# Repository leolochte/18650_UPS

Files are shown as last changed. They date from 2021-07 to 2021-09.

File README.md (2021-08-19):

# 18650 UPS
My goal with this project is to power my development boards and experiments from a rechargable battery, so remaining a small footprint is obviously a key target. Ideally, the board should include conveniences like monitoring the power consumption and battery life. Charging should be done with standard USB Micro-B.

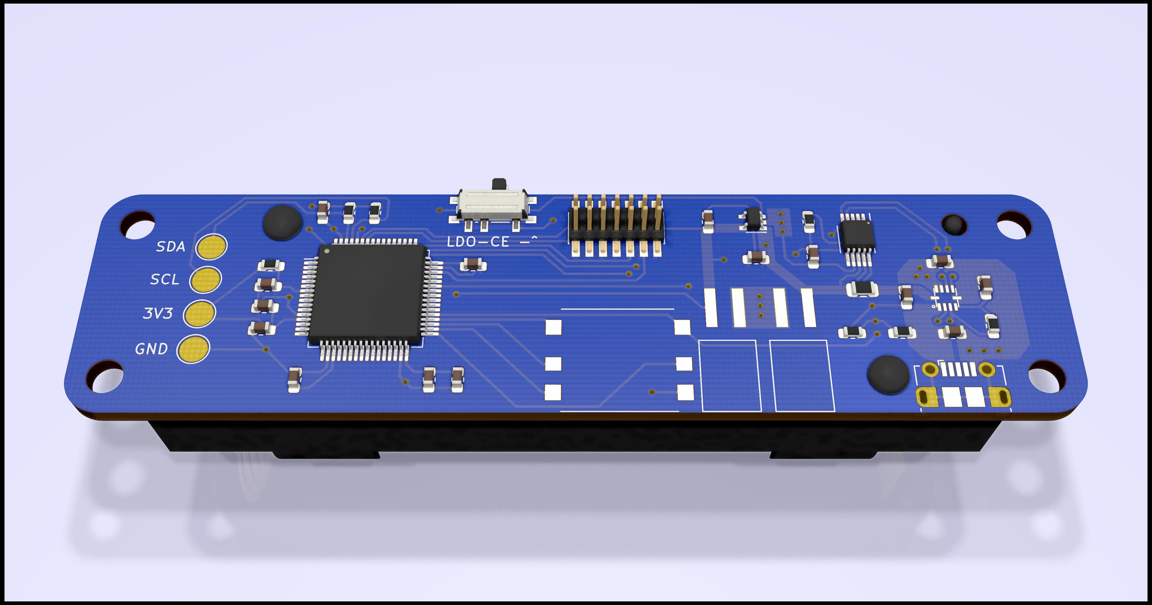
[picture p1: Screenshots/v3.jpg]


# Description
I decided for 18650 Li-Ion Cells as they are widely available and provide high capacity. Due to their metal casing they are also more robust than normal hobby grade LiPo batteries.
Of course, there are countless 18650 compatible supply boards for projects already, but they all miss certain features or raise serious quality and safety concerns.

So i set out to design my own PCB that mounts directly to the back of a single cell holder.

# Safety
As all Li-Ion batteries should be treated with great care, my desired safety features are:

- Overcharge cutoff
- Safety timer during charge phase
- Overcurrent protection / Current limiting
- Short circuit protection
- **Configurable** Under-voltge cutoff
- Battery disconnect during storage
- Temperature warnings

# Part Selection

- **MP2667**        - I2C programmable Charge IC with heaps of safety features and output current limiting
- **INA237**        - 16-Bit current, power, temperature and voltage monitor with I2C Interface
- **STM32L151RCT6** - Simply because i had them lying around
- **1.3" OLED**     - To configure the charger and display sensor data

# Current State Of Project

The non-ideal switchmode regulator layout and method of seperatig the chargin IC and protection IC resulted in problems. In the current version switchmodes are omitted and all safety features are integrated in one high quality IC. The monitoring capabilities have been enhanced and a bigger display replaced the old one.

All parts for version 3 are ordered. Patiently waiting for snail post to arrive...

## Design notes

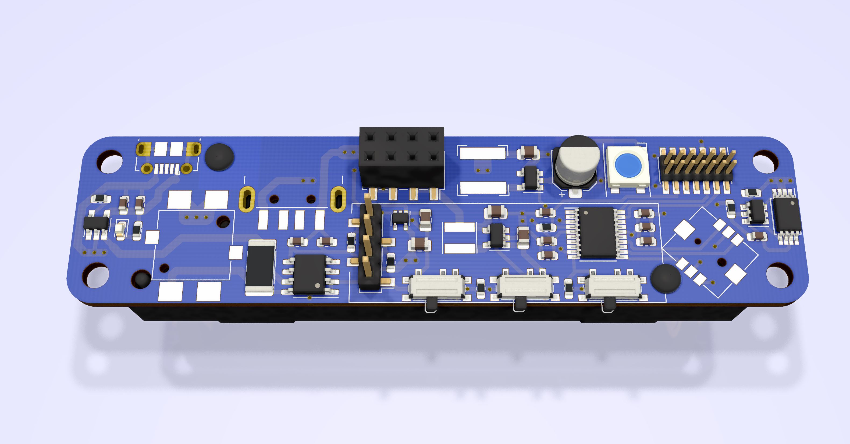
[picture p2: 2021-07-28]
Screenshots/V2.JPG

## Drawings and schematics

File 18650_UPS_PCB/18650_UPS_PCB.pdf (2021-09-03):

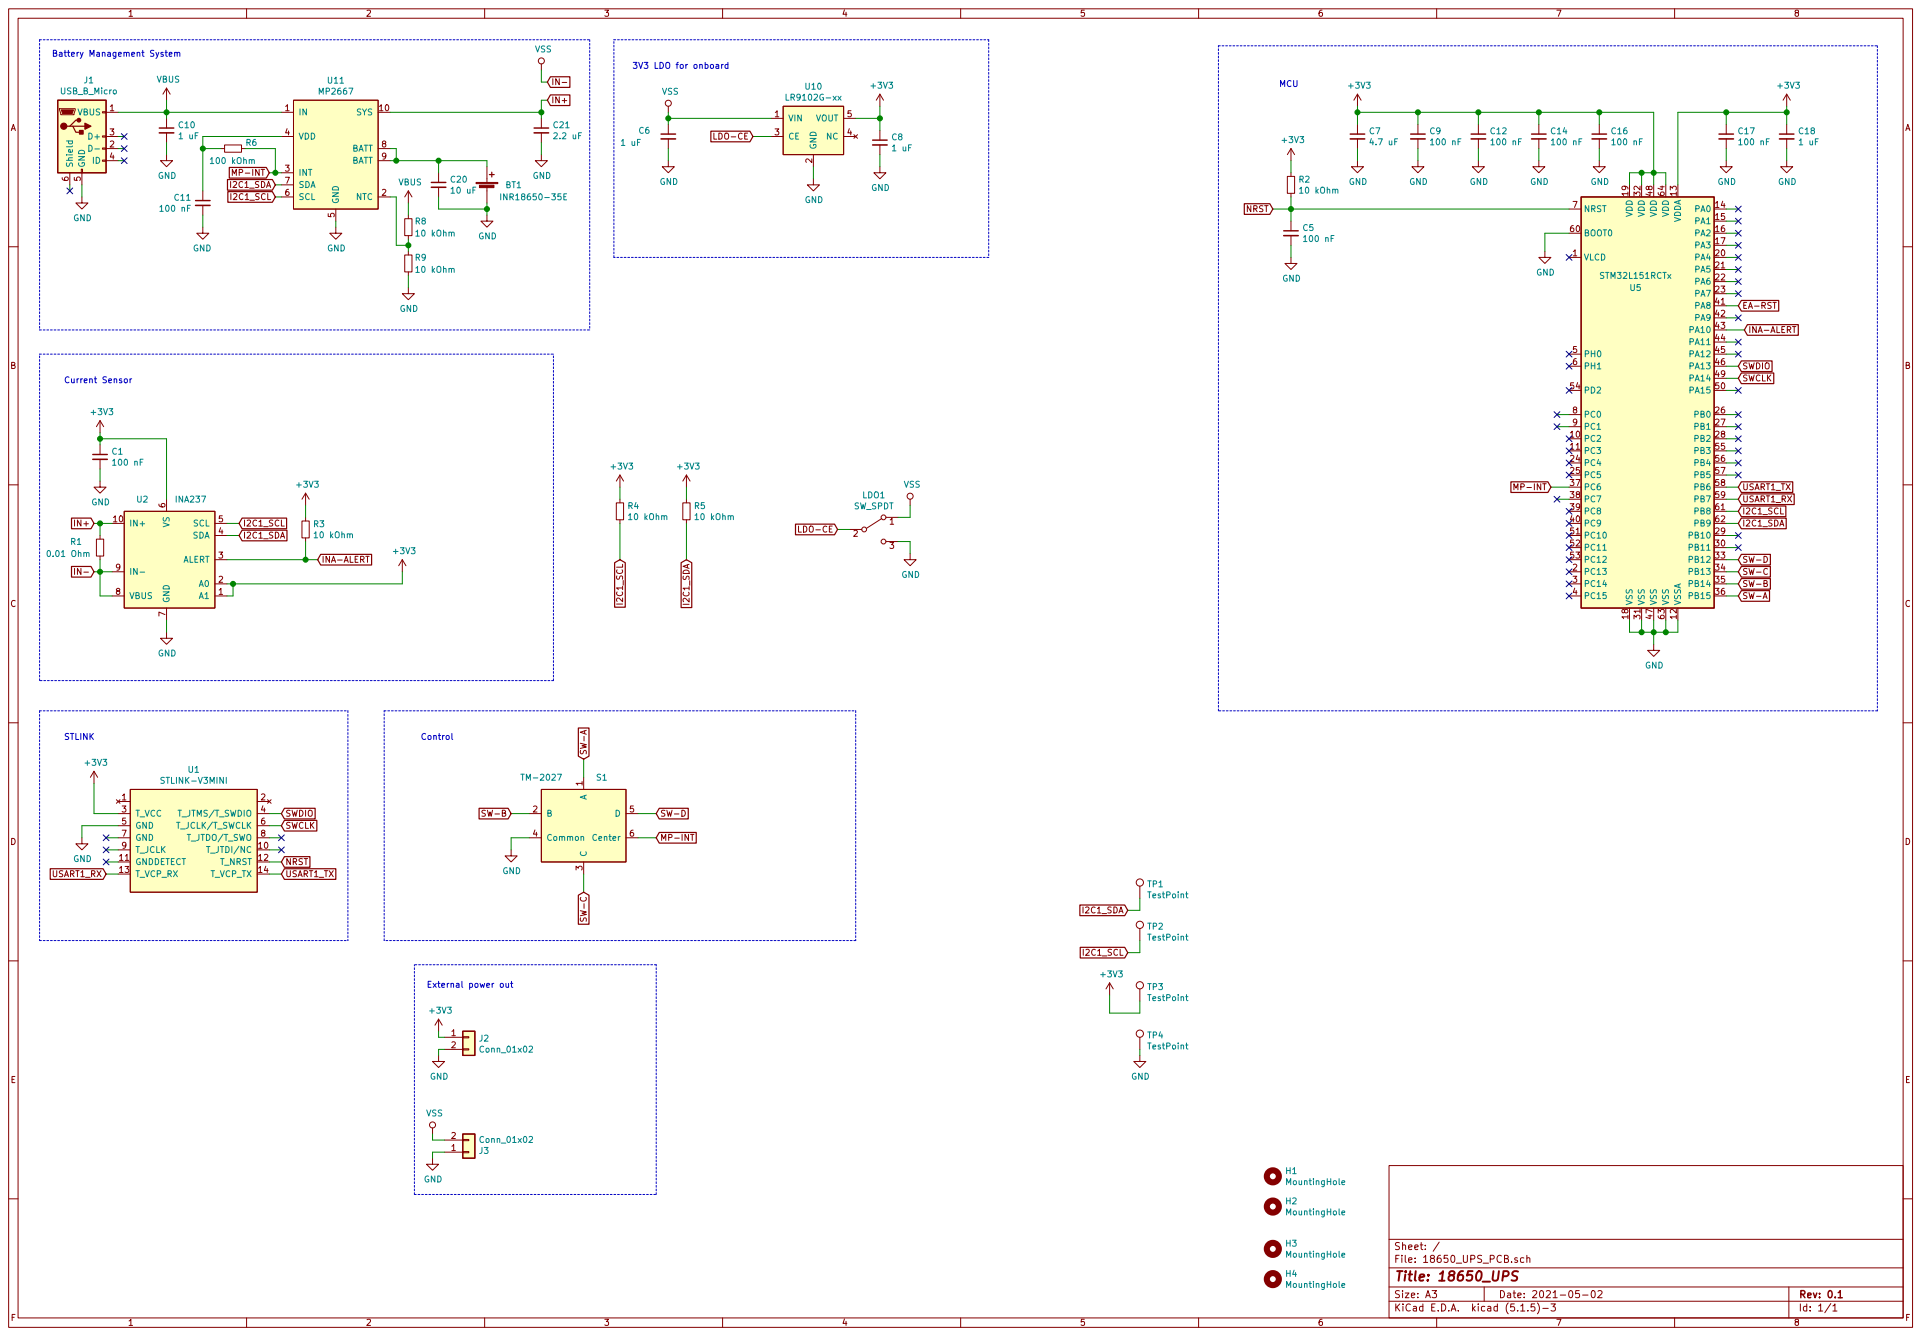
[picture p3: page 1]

3V3 LDO for onboard Battery Management System

5 SCL 6 SDA 7 BATT 8 BATT 9 U11 MP2667 A1 1

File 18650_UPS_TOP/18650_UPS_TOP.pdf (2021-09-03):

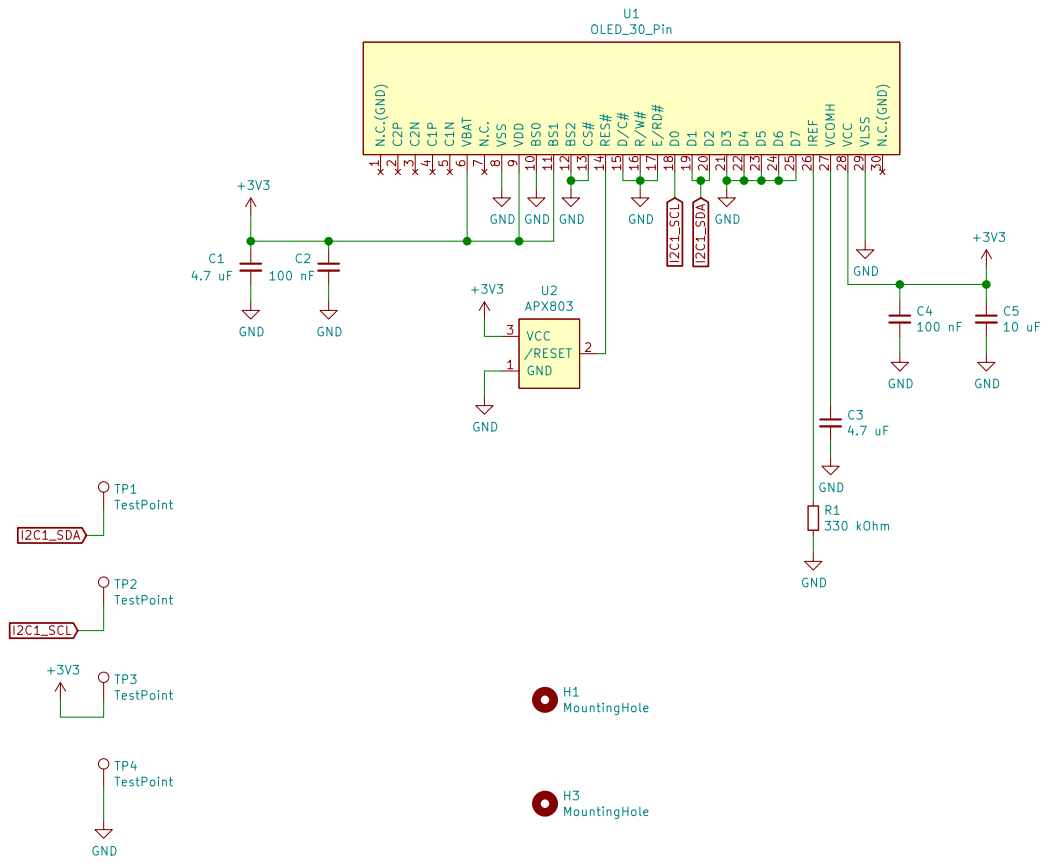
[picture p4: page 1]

9 U1 OLED_30_Pin +3V3 TP3 TestPoint TP4 TestPoint TP2 TestPoint TP1 TestPoint H3MountingHole

2 D2 20 D3 21 D4 22 D5 23 D6 24 D7 25 IREF 26 VCOMH 27 VCC 28 VLSS 29 C2N

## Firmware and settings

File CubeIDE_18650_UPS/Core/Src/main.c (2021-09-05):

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
/* Includes ------------------------------------------------------------------*/
#include "main.h"

/* USER CODE BEGIN Includes */
#include "ssd1306.h"
#include "stdio.h"
/* USER CODE END Includes */

I2C_HandleTypeDef hi2c1;

TIM_HandleTypeDef htim2;

UART_HandleTypeDef huart1;

/* USER CODE BEGIN PV */
uint8_t aRxBuffer[3];
uint8_t TxBuffer[2];
char charBuffer[20];
uint16_t temp;

volatile uint8_t read_state = 0;
uint8_t state_SW_U = 0;
uint8_t state_SW_D = 0;
uint8_t state_SW_L = 0;
uint8_t state_SW_R = 0;

volatile uint8_t contrast = 0xFF;
volatile uint8_t charge_enable = 1;
volatile uint8_t usb_version = 2;
/* USER CODE END PV */

void SystemClock_Config(void);
static void MX_GPIO_Init(void);
static void MX_USART1_UART_Init(void);
static void MX_I2C1_Init(void);
static void MX_TIM2_Init(void);
/**
  * @brief  The application entry point.
  * @retval int
  */
int main(void)
{
  /* MCU Configuration--------------------------------------------------------*/

  /* Reset of all peripherals, Initializes the Flash interface and the Systick. */
  HAL_Init();

  /* Configure the system clock */
  SystemClock_Config();

  /* Initialize all configured peripherals */
  MX_GPIO_Init();
  MX_USART1_UART_Init();
  MX_I2C1_Init();
  MX_TIM2_Init();
  /* USER CODE BEGIN 2 */
  ssd1306_Init();

  //resetting ina237
  TxBuffer[0] = 0x80;
  TxBuffer[1] = 0x00;
  HAL_I2C_Mem_Write(&hi2c1, 0x45<<1, 0x00, 1, TxBuffer, sizeof(TxBuffer), 1000);

  //setting adc range
  TxBuffer[0] = 0x00;
  TxBuffer[1] = 0x10;
  HAL_I2C_Mem_Write(&hi2c1, 0x45<<1, 0x00, 1, TxBuffer, sizeof(TxBuffer), 1000);

  //calibrating shunt register
  TxBuffer[0] = 0x07;
  TxBuffer[1] = 0xD0;
  HAL_I2C_Mem_Write(&hi2c1, 0x45<<1, 0x02, 1, TxBuffer, sizeof(TxBuffer), 1000);

  //adc_config
  HAL_I2C_Mem_Read(&hi2c1, 0x45<<1, 0x01, 1, aRxBuffer, sizeof(aRxBuffer), 1000);
  temp = (aRxBuffer[0]<<8) | aRxBuffer[1];
  TxBuffer[0] = aRxBuffer[0];
  TxBuffer[1] = aRxBuffer[1] | 0x05;
  HAL_I2C_Mem_Write(&hi2c1, 0x45<<1, 0x01, 1, TxBuffer, sizeof(TxBuffer), 1000);

  //charge config default
  HAL_I2C_Mem_Read(&hi2c1, 0x09<<1, 0x01, 1, aRxBuffer, sizeof(aRxBuffer), 1000);
  TxBuffer[0] = 0b00000100; 	//charge enable and UVLO 2.8V
  TxBuffer[1] = 0x00;
  HAL_I2C_Mem_Write(&hi2c1, 0x09<<1, 0x01, 1, TxBuffer, 1, 1000);
  HAL_I2C_Mem_Read(&hi2c1, 0x09<<1, 0x01, 1, aRxBuffer, sizeof(aRxBuffer), 1000);

  //setting initial charge curretn to usb 2 compliant
  TxBuffer[0] = 0b01001011;
  TxBuffer[1] = 0x00;
  HAL_I2C_Mem_Write(&hi2c1, 0x09<<1, 0x00, 1, TxBuffer, 1, 1000);
  TxBuffer[0] = 0b00001110;
  TxBuffer[1] = 0x00;
  HAL_I2C_Mem_Write(&hi2c1, 0x09<<1, 0x02, 1, TxBuffer, 1, 1000);

  /* USER CODE END 2 */

  /* Infinite loop */
  /* USER CODE BEGIN WHILE */
  while (1)
  {
    /* USER CODE END WHILE */

    /* USER CODE BEGIN 3 */


	  ssd1306_Fill(Black);

	  switch (read_state) {
	  	  case 0:
	  		  //vbus
			  HAL_I2C_Mem_Read(&hi2c1, 0x45<<1, 0x05, 1, aRxBuffer, sizeof(aRxBuffer), 1000);
			  temp = 3.125*(float)((aRxBuffer[0]<<8) | aRxBuffer[1]);
			  sprintf(charBuffer, "%u mV", temp);
			  ssd1306_SetCursor(0, 14);
			  ssd1306_WriteString(charBuffer, Font_11x18, White);
			  sprintf(charBuffer, "Voltage:");
			  ssd1306_SetCursor(0, 0);
			  ssd1306_WriteString(charBuffer, Font_7x10, White);
			  ssd1306_DrawRectangle(124, 0, 127, 3, White);
			  ssd1306_DrawRectangle(125, 1, 126, 2, White);
	  		  break;
	  	  case 1:
			  //current
			  HAL_I2C_Mem_Read(&hi2c1, 0x45<<1, 0x07, 1, aRxBuffer, sizeof(aRxBuffer), 1000);
			  temp = 0.0610352*(float)((aRxBuffer[0]<<8) | aRxBuffer[1]);
			  sprintf(charBuffer, "%u mA", temp);
			  ssd1306_SetCursor(0, 14);
			  ssd1306_WriteString(charBuffer, Font_11x18, White);
			  sprintf(charBuffer, "Current output:");
			  ssd1306_SetCursor(0, 0);
			  ssd1306_WriteString(charBuffer, Font_7x10, White);
			  ssd1306_DrawRectangle(124, 4, 127, 7, White);
			  ssd1306_DrawRectangle(125, 5, 126, 6, White);
	  		  break;
	  	  case 2:
			  //power
			  HAL_I2C_Mem_Read(&hi2c1, 0x45<<1, 0x08, 1, aRxBuffer, sizeof(aRxBuffer), 1000);
			  temp = 0.2*0.0610352*(float)((aRxBuffer[0]<<16) | aRxBuffer[1]<<8 | aRxBuffer[0]);
			  sprintf(charBuffer, "%u mW", temp);
			  ssd1306_SetCursor(0, 14);
			  ssd1306_WriteString(charBuffer, Font_11x18, White);
			  sprintf(charBuffer, "Power output:");
			  ssd1306_SetCursor(0, 0);
			  ssd1306_WriteString(charBuffer, Font_7x10, White);
			  ssd1306_DrawRectangle(124, 8, 127, 11, White);
			  ssd1306_DrawRectangle(125, 9, 126, 10, White);
			  break;
	  	  case 3:
			  //dietemp
			  HAL_I2C_Mem_Read(&hi2c1, 0x45<<1, 0x06, 1, aRxBuffer, sizeof(aRxBuffer), 1000);
			  temp = 0.125*(float)((aRxBuffer[0]<<8) | aRxBuffer[1]);
			  temp = temp>>4;
			  sprintf(charBuffer, "%u C", temp);
			  ssd1306_SetCursor(0, 14);
			  ssd1306_WriteString(charBuffer, Font_11x18, White);
			  sprintf(charBuffer, "Board temperature:");
			  ssd1306_SetCursor(0, 0);
			  ssd1306_WriteString(charBuffer, Font_7x10, White);
			  ssd1306_DrawRectangle(124, 12, 127, 15, White);
			  ssd1306_DrawRectangle(125, 13, 126, 14, White);
			  break;
	  	  case 4:
			  //charge status
			  HAL_I2C_Mem_Read(&hi2c1, 0x09<<1, 0x07, 1, aRxBuffer, sizeof(aRxBuffer), 1000);
			  temp = (aRxBuffer[0] & 0b00011000)>>3;
			  switch (temp) {
				  case 0:
					  sprintf(charBuffer, "No charger");
					  ssd1306_SetCursor(0, 14);
					  ssd1306_WriteString(charBuffer, Font_11x18, White);
					  break;
				  case 1:
					  sprintf(charBuffer, "Pre charge");
					  ssd1306_SetCursor(0, 14);
					  ssd1306_WriteString(charBuffer, Font_11x18, White);
					  break;
				  case 2:
					  sprintf(charBuffer, "Charging...");
					  ssd1306_SetCursor(0, 14);
					  ssd1306_WriteString(charBuffer, Font_11x18, White);
					  break;
				  case 3:
					  sprintf(charBuffer, "Done!");
					  ssd1306_SetCursor(0, 14);
					  ssd1306_WriteString(charBuffer, Font_11x18, White);
					  break;
				  default:
					  break;
			  }
			  sprintf(charBuffer, "Charge status:");
			  ssd1306_SetCursor(0, 0);
			  ssd1306_WriteString(charBuffer, Font_7x10, White);
			  ssd1306_DrawRectangle(124, 16, 127, 19, White);
			  ssd1306_DrawRectangle(125, 17, 126, 18, White);
			  break;
		  case 5:
			  if (charge_enable == 0) {
				  sprintf(charBuffer, "OFF");
				  ssd1306_SetCursor(1, 14);
				  ssd1306_WriteString(charBuffer, Font_11x18, Black);
				  sprintf(charBuffer, "ON ");
				  ssd1306_SetCursor(38, 14);
				  ssd1306_WriteString(charBuffer, Font_11x18, White);
			  } else if (charge_enable == 1) {
				  sprintf(charBuffer, "OFF");
				  ssd1306_SetCursor(1, 14);
				  ssd1306_WriteString(charBuffer, Font_11x18, White);
				  sprintf(charBuffer, "ON ");
				  ssd1306_SetCursor(38, 14);
				  ssd1306_WriteString(charBuffer, Font_11x18, Black);
			  }
			  ssd1306_DrawRectangle(0, 13, 70, 31, White);


			  sprintf(charBuffer, "Charge control:");
			  ssd1306_SetCursor(0, 0);
			  ssd1306_WriteString(charBuffer, Font_7x10, White);
			  ssd1306_DrawRectangle(124, 20, 127, 23, White);
			  ssd1306_DrawRectangle(125, 21, 126, 22, White);
			  break;
		  case 6:
			  if (usb_version == 2) {
				  sprintf(charBuffer, "0.5A");
				  ssd1306_SetCursor(1, 14);
				  ssd1306_WriteString(charBuffer, Font_11x18, Black);
				  sprintf(charBuffer, "1.0A");
				  ssd1306_SetCursor(50, 14);
				  ssd1306_WriteString(charBuffer, Font_11x18, White);
			  } else if (usb_version == 3) {
				  sprintf(charBuffer, "0.5A");
				  ssd1306_SetCursor(1, 14);
				  ssd1306_WriteString(charBuffer, Font_11x18, White);
				  sprintf(charBuffer, "1.0A ");
				  ssd1306_SetCursor(50, 14);
				  ssd1306_WriteString(charBuffer, Font_11x18, Black);
			  }
			  ssd1306_DrawRectangle(0, 13, 104, 31, White);

			  sprintf(charBuffer, "USB current limit:");
			  ssd1306_SetCursor(0, 0);
			  ssd1306_WriteString(charBuffer, Font_7x10, White);
			  ssd1306_DrawRectangle(124, 24, 127, 27, White);
			  ssd1306_DrawRectangle(125, 25, 126, 26, White);
			  break;
		  case 7:
			  switch (contrast) {
				  case 255:
					  sprintf(charBuffer, "100");
					  break;
				  case 191:
					  sprintf(charBuffer, "75");
					  break;
				  case 127:
					  sprintf(charBuffer, "50");
					  break;
				  case 63:
					  sprintf(charBuffer, "25");
					  break;
				  case 0:
					  sprintf(charBuffer, "0");
					  break;
				  default:
					  break;
			  }

			  ssd1306_SetCursor(0, 14);
			  ssd1306_WriteString(charBuffer, Font_11x18, White);
			  sprintf(charBuffer, "Screen brightness:");
			  ssd1306_SetCursor(0, 0);
			  ssd1306_WriteString(charBuffer, Font_7x10, White);
			  ssd1306_DrawRectangle(124, 28, 127, 31, White);
			  ssd1306_DrawRectangle(125, 29, 126, 30, White);
		  	  break;
	  	  default:
		  	  break;
	  }

	  ssd1306_UpdateScreen();

	  HAL_Delay(100);
  }
  /* USER CODE END 3 */
}

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
/* USER CODE BEGIN 4 */
void HAL_GPIO_EXTI_Callback(uint16_t GPIO_Pin) {
	switch (GPIO_Pin) {
		case SW_U_Pin:
			state_SW_U = 1;
			HAL_TIM_Base_Start_IT(&htim2);
			break;
		case SW_D_Pin:
			state_SW_D = 1;
			HAL_TIM_Base_Start_IT(&htim2);
			break;
		case SW_L_Pin:
			state_SW_L = 1;
			HAL_TIM_Base_Start_IT(&htim2);
			break;
		case SW_R_Pin:
			state_SW_R = 1;
			HAL_TIM_Base_Start_IT(&htim2);
			break;
		default:
			break;
	}
}

void HAL_TIM_PeriodElapsedCallback(TIM_HandleTypeDef *htim)
{
  if (htim == &htim2) {
	 if (state_SW_U == 1 && HAL_GPIO_ReadPin(SW_U_GPIO_Port, SW_U_Pin) == GPIO_PIN_RESET) {
		 state_SW_U = 0;
		 HAL_TIM_Base_Stop_IT(&htim2);

		 if (read_state == 0) {
			 //read_state = 7;
		 } else {
			 read_state--;
		 }
	 }
	 if (state_SW_D == 1 && HAL_GPIO_ReadPin(SW_D_GPIO_Port, SW_D_Pin) == GPIO_PIN_RESET) {
		 state_SW_D = 0;
		 HAL_TIM_Base_Stop_IT(&htim2);

		 if (read_state == 7) {
			 //read_state = 0;
		 } else {
			 read_state++;
		 }
	 }
	 if (state_SW_L == 1 && HAL_GPIO_ReadPin(SW_L_GPIO_Port, SW_L_Pin) == GPIO_PIN_RESET) {
		 state_SW_L = 0;
		 HAL_TIM_Base_Stop_IT(&htim2);

		 switch (read_state) {
		 	 case 5:
		 		 charge_enable = 0;

		 		 HAL_I2C_Mem_Read(&hi2c1, 0x09<<1, 0x01, 1, aRxBuffer, sizeof(aRxBuffer), 1000);
		 		 TxBuffer[0] = aRxBuffer[0] | 0b00001000;
		 		 TxBuffer[1] = 0x00;
		 		 HAL_I2C_Mem_Write(&hi2c1, 0x09<<1, 0x01, 1, TxBuffer, 1, 1000);
		 		 HAL_I2C_Mem_Read(&hi2c1, 0x09<<1, 0x01, 1, aRxBuffer, sizeof(aRxBuffer), 1000);
		 		 break;
		 	 case 6:
		 		 usb_version = 2;
		 		 TxBuffer[0] = 0b01001011;
				 TxBuffer[1] = 0x00;
				 HAL_I2C_Mem_Write(&hi2c1, 0x09<<1, 0x00, 1, TxBuffer, 1, 1000);
				 TxBuffer[0] = 0b00001110;
				 TxBuffer[1] = 0x00;
				 HAL_I2C_Mem_Write(&hi2c1, 0x09<<1, 0x02, 1, TxBuffer, 1, 1000);
		 		 break;
		 	 case 7:
		 		 if (contrast > 63) {
		 			 contrast = contrast-64;
		 		 	 ssd1306_SetContrast(contrast);
		 		 } else if (contrast == 63) {
		 			 contrast = contrast-63;
		 			 ssd1306_SetContrast(contrast);
		 		 }
		 		 break;
		 	 default:
		 		 break;
		 }


	 }
	 if (state_SW_R == 1 && HAL_GPIO_ReadPin(SW_R_GPIO_Port, SW_R_Pin) == GPIO_PIN_RESET) {
		 state_SW_R = 0;
		 HAL_TIM_Base_Stop_IT(&htim2);

		 switch (read_state) {
		 	 case 5:
		 		 charge_enable = 1;
		 		 HAL_I2C_Mem_Read(&hi2c1, 0x09<<1, 0x01, 1, aRxBuffer, sizeof(aRxBuffer), 1000);
				 TxBuffer[0] = aRxBuffer[0] & 0b11110111;
				 TxBuffer[1] = 0x00;
				 HAL_I2C_Mem_Write(&hi2c1, 0x09<<1, 0x01, 1, TxBuffer, 1, 1000);
				 HAL_I2C_Mem_Read(&hi2c1, 0x09<<1, 0x01, 1, aRxBuffer, sizeof(aRxBuffer), 1000);
		 		 break;
		 	 case 6:
		 		 usb_version = 3;
		 		 TxBuffer[0] = 0b01001111;
				 TxBuffer[1] = 0x00;
				 HAL_I2C_Mem_Write(&hi2c1, 0x09<<1, 0x00, 1, TxBuffer, 1, 1000);
				 TxBuffer[0] = 0b00011100;
				 TxBuffer[1] = 0x00;
				 HAL_I2C_Mem_Write(&hi2c1, 0x09<<1, 0x02, 1, TxBuffer, 1, 1000);
		 		 break;
		 	 case 7:
		 		 if (contrast == 0) {
		 			 contrast = contrast+63;
		 		 	 ssd1306_SetContrast(contrast);
		 		 } else if (contrast > 0 && contrast != 255) {
		 			 contrast = contrast+64;
					 ssd1306_SetContrast(contrast);
		 		 }
		 		 break;
		 	 default:
		 		 break;
		 }
	 }
  }
}
/* USER CODE END 4 */
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


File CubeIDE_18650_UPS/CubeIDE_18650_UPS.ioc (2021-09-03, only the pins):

Mcu.UserName=STM32L151RCTx
PA13.Signal=SYS_JTMS-SWDIO
PA14.Signal=SYS_JTCK-SWCLK
PB12.GPIO_Label=SW_R
PB12.Signal=GPXTI12
PB13.GPIO_Label=SW_D
PB13.Signal=GPXTI13
PB14.GPIO_Label=SW_L
PB14.Signal=GPXTI14
PB15.GPIO_Label=SW_U
PB15.Signal=GPXTI15
PB6.Signal=USART1_TX
PB7.Signal=USART1_RX
PB8.Signal=I2C1_SCL
PB9.Signal=I2C1_SDA

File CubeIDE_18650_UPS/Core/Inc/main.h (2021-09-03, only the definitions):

#define SW_R_Pin GPIO_PIN_12
#define SW_R_GPIO_Port GPIOB
#define SW_R_EXTI_IRQn EXTI15_10_IRQn
#define SW_D_Pin GPIO_PIN_13
#define SW_D_GPIO_Port GPIOB
#define SW_D_EXTI_IRQn EXTI15_10_IRQn
#define SW_L_Pin GPIO_PIN_14
#define SW_L_GPIO_Port GPIOB
#define SW_L_EXTI_IRQn EXTI15_10_IRQn
#define SW_U_Pin GPIO_PIN_15
#define SW_U_GPIO_Port GPIOB
#define SW_U_EXTI_IRQn EXTI15_10_IRQn

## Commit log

2021-05-01 created kicad project
    [18650_UPS_PCB.kicad_pcb, 18650_UPS_PCB.sch]
2021-05-02 added main components
    [18650_UPS_PCB.sch]
2021-05-03 reworked schematic
    [18650_UPS_PCB.sch]
2021-05-05 moved some components around and added st link
    [18650_UPS_PCB.sch]
2021-05-10 removed IoT board connectors
    [18650_UPS_PCB.kicad_pcb, 18650_UPS_PCB.sch, connectors.sch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]
2021-05-12 first routing done
    [18650_UPS_PCB.kicad_pcb, 18650_UPS_PCB.sch, mcu_sense.sch]
2021-05-12 test of branch
    [18650_UPS_PCB.sch]
2021-05-13 layout almost done
    [18650_UPS_PCB.kicad_pcb, 18650_UPS_PCB.sch, connectors.sch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]
2021-05-17 routing done
    [18650_UPS_PCB.kicad_pcb, 18650_UPS_PCB.sch, power.sch]
2021-05-17 schematic organizing
    [18650_UPS_PCB.sch]
2021-05-17 changed resistor values tps63000
    [18650_UPS_PCB.kicad_pcb, 18650_UPS_PCB.sch, BOM.xlsx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]
2021-05-24 deleted lcsc shopping cart files
    [LCSC_Exported_20210517_180502.xlsx, LCSC_Exported_20210517_183229.xlsx, LCSC_Exported_20210517_221247.xlsx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]
2021-06-12 removed some not needed files
    [external.sch, rpi.sch]
2021-06-12 v2 layout started
    [18650_UPS_PCB.kicad_pcb, 18650_UPS_PCB.sch, power.sch]
2021-06-12 all components on board
    [18650_UPS_PCB.kicad_pcb, 18650_UPS_PCB.sch]
2021-06-17 v2 layout complete and started routing
    [18650_UPS_PCB.kicad_pcb, 18650_UPS_PCB.sch]
2021-06-21 1 net left
    [18650_UPS_PCB.kicad_pcb]
2021-06-21 routing cleanup
    [18650_UPS_PCB.kicad_pcb]
2021-06-22 cleaned routing significantly
    [18650_UPS_PCB.kicad_pcb, 18650_UPS_PCB.sch]
2021-06-22 v2 ordered
    [18650_UPS_PCB-B_Cu.gbr, 18650_UPS_PCB-B_Mask.gbr, 18650_UPS_PCB-B_Paste.gbr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]
2021-07-29 base for v2 with new bms and sense ic
    [18650_UPS_PCB.kicad_pcb, 18650_UPS_PCB.sch]
2021-07-30 reworked schematic with new components
    5V Boost missing
    [18650_UPS_PCB.sch]
2021-07-30 schematic done
    [18650_UPS_PCB.sch]
2021-07-30 savepoint before messing up pcbnew
    [18650_UPS_PCB.kicad_pcb, 18650_UPS_PCB.sch]
2021-07-31 all parts on pcb
    [18650_UPS_PCB.kicad_pcb, 18650_UPS_PCB.sch]
2021-08-01 placed all components
    [18650_UPS_PCB.kicad_pcb, 18650_UPS_PCB.sch]
2021-08-02 changed to ina 237/239
    [18650_UPS_PCB.kicad_pcb, 18650_UPS_PCB.sch]
2021-08-02 minor changes in layout
    [18650_UPS_PCB.kicad_pcb, 18650_UPS_PCB.sch]
2021-08-02 added silkscreen markings
    [18650_UPS_PCB.kicad_pcb, 18650_UPS_PCB.sch]
2021-08-04 savepoint before messing schematic up
    [18650_UPS_PCB.sch]
2021-08-07 Major Overhaul
    Changed Buttons, Display changed to OLED and moved to top PCB
    [18650_UPS_PCB.kicad_pcb, 18650_UPS_PCB.sch, 18650_UPS_TOP.kicad_pcb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]
2021-08-08 Started routing V3
    [18650_UPS_PCB.kicad_pcb, 18650_UPS_PCB.sch]
2021-08-08 Finished routing
    [18650_UPS_PCB.kicad_pcb, 18650_UPS_PCB.sch]
2021-08-10 changed buttons
    [18650_UPS_PCB.kicad_pcb, 18650_UPS_PCB.sch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]
2021-08-11 changed back to 5-way-tactile
    [18650_UPS_PCB.kicad_pcb, 18650_UPS_PCB.sch]
2021-08-11 rearranged capacitors slightly
    [18650_UPS_PCB.kicad_pcb]
2021-08-11 ordered pcbs
    [18650_UPS_PCB-B_Cu.gbr, 18650_UPS_PCB-B_Mask.gbr, 18650_UPS_PCB-B_Paste.gbr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]
2021-09-03 added CubeIDE project
    [18650_UPS.cfg]
2021-09-03 added readout of shunt voltage and current
2021-09-05 ingnoring some settings files
    [18650_UPS.cfg]
2021-09-05 fixed compiler warnings on sprintf
    [main.c]

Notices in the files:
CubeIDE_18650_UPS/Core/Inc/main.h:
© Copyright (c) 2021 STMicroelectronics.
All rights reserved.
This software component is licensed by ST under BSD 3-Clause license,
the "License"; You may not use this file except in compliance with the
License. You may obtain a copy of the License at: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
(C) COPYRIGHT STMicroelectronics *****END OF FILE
